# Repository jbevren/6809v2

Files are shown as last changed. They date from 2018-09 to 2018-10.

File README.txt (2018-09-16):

6809v2 single-board computer

(c) 2018 David Wood

This system is a 3.68mhz 6809-based microcomputer with 128k RAM and 8K rom.  It is intended to run 6809-based operating systems that run within 64k of RAM such as FLEX or OS-9 Level I.

All I/O services are provided via a 68681 DUART, either via one of its serial ports or via the extra GPIO pins on the device.

This documentation is primarily a placeholder and will likely be improved as time goes on(TM). ;-)

System memory map:

0000-DFFF	System RAM
E000-FEFF	System ROM  (ROMON=high) or System RAM(ROMON=low)
FF00-FF0F	68681 DUART (see below for I/O definitions)
FF10-FFDF	reserved: Don't use
FFE0-FFFF	System ROM  (ROMON=high) or System RAM(ROMON=low)

DUART I/O Map:
IP0		CTS port A
IP1		CTS port B
IP2		DCD port A (not routed)
IP3		DCD port B (not routed)
IP4		n/c
IP5		SD Data input	Input from Micro SD

OP0		RTS port A
OP1		RTS port B
OP2		RAM A16		A16 to RAM
OP3		RAM A17		A17 to RAM (128k has CE2 here)
OP4		ROMON		High enables the 2764 eprom
OP5		SDCK		Clock output to Micro SD
OP6		SDDO		Data output to Micro SD
OP7		SDCS		Chip select output to Micro SD
		NOTE: The 68681 sets all outputs high on reset
		NOTE: The 68681 inverts its output port bits

A summary of programming-related information is also printed on the pcb.

The memory fitted with a standard 128k-256k sram.  A 512k device can be fitted but the board lacks sufficient hardware to bankswitch more than 256k.
A jumper bridge under the SRAM will allow disconnecting A18 from ground.

Directories:
kicad/		Kicad v<5.0 files used to design the board
sbug/		S-BUG port to the 6809v2 SBC (working)
tests/		Prototype test code segments
sdcard/		SD-Card code (not yet finished)

** Many thanks to Dolo@hackaday.IO for the sdcard sample code and permission for the author to use it as long as the code for the firmware remains free and open! **

License: CC:SA license v4.0
I encourage the sharing and adaptation of this design as long as some credit to me is given in the firmware and/or board design.

Reach me at jbevren@gmail.com

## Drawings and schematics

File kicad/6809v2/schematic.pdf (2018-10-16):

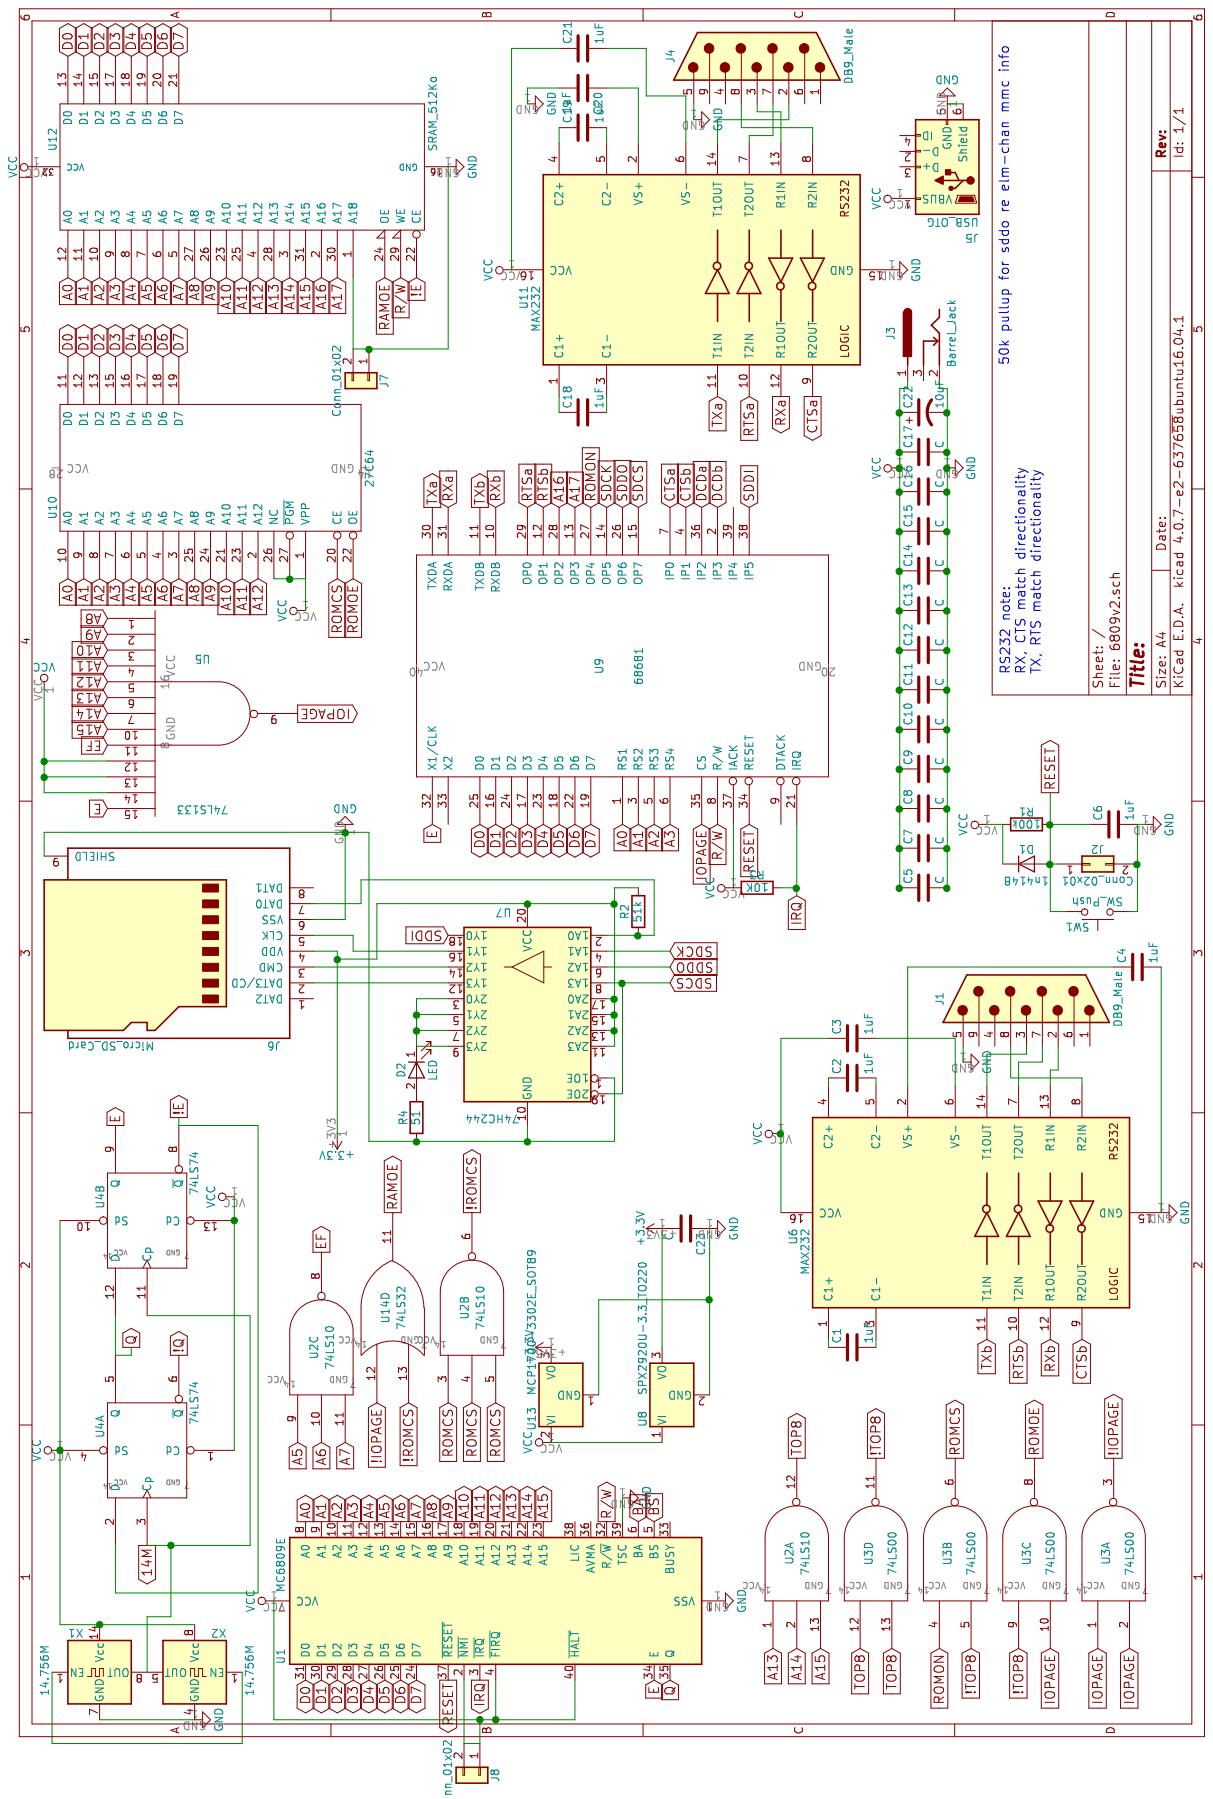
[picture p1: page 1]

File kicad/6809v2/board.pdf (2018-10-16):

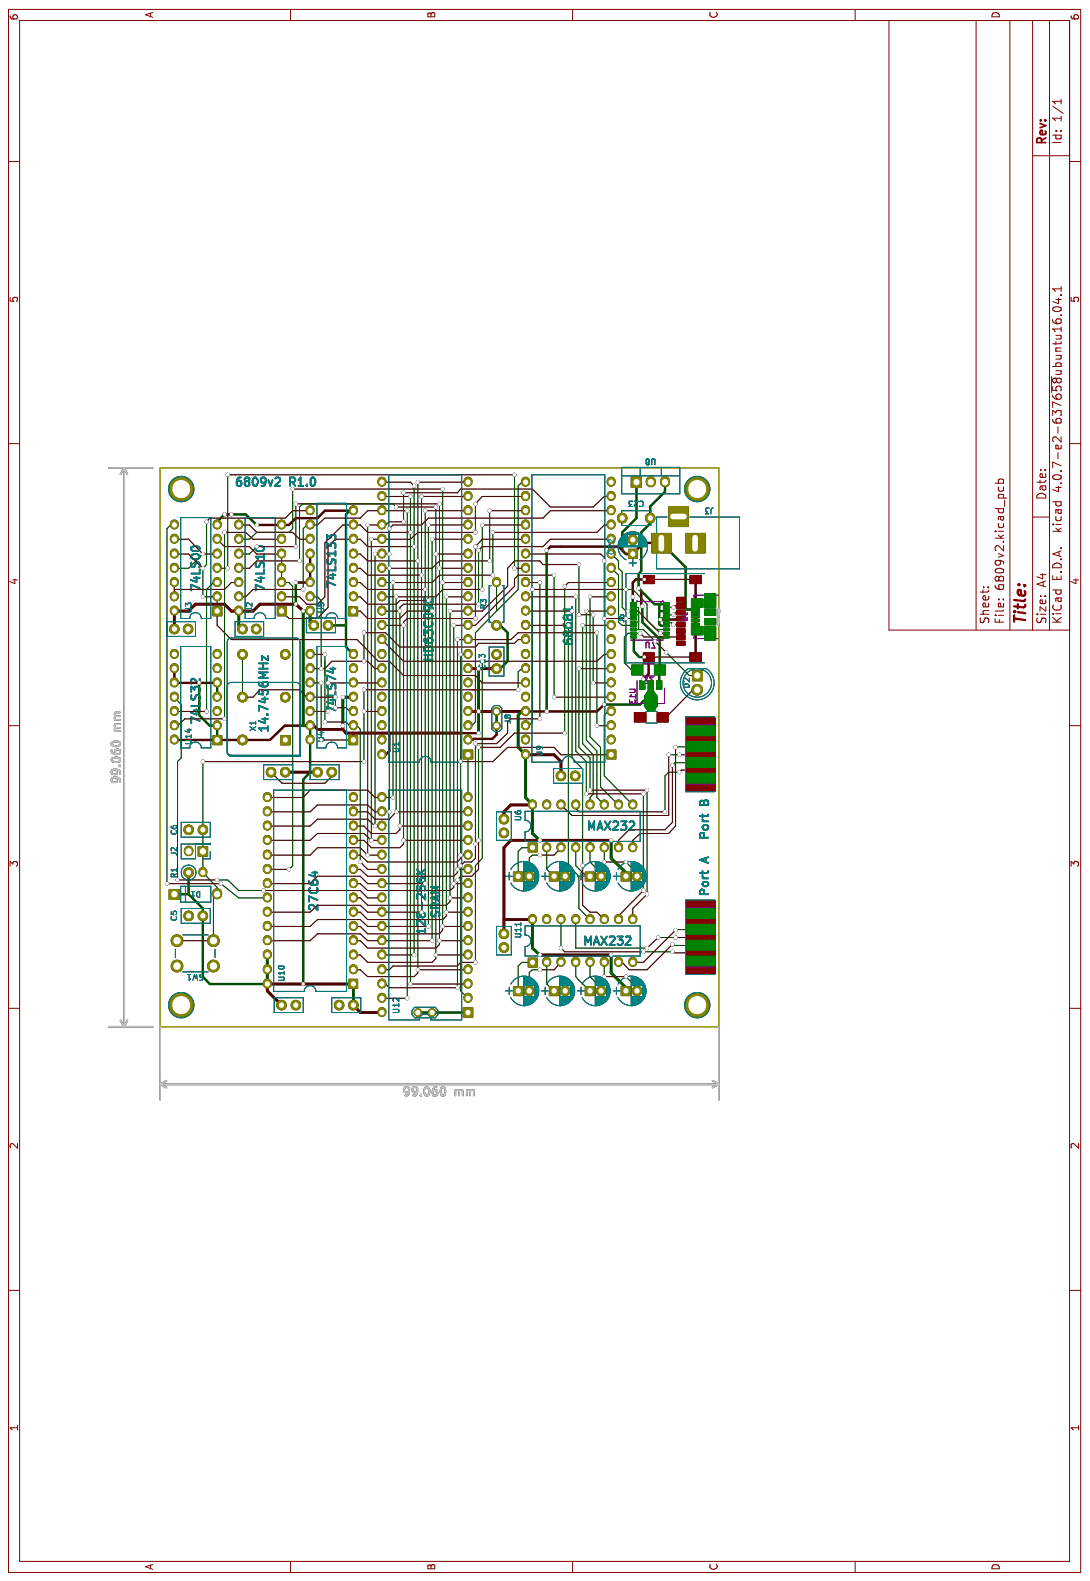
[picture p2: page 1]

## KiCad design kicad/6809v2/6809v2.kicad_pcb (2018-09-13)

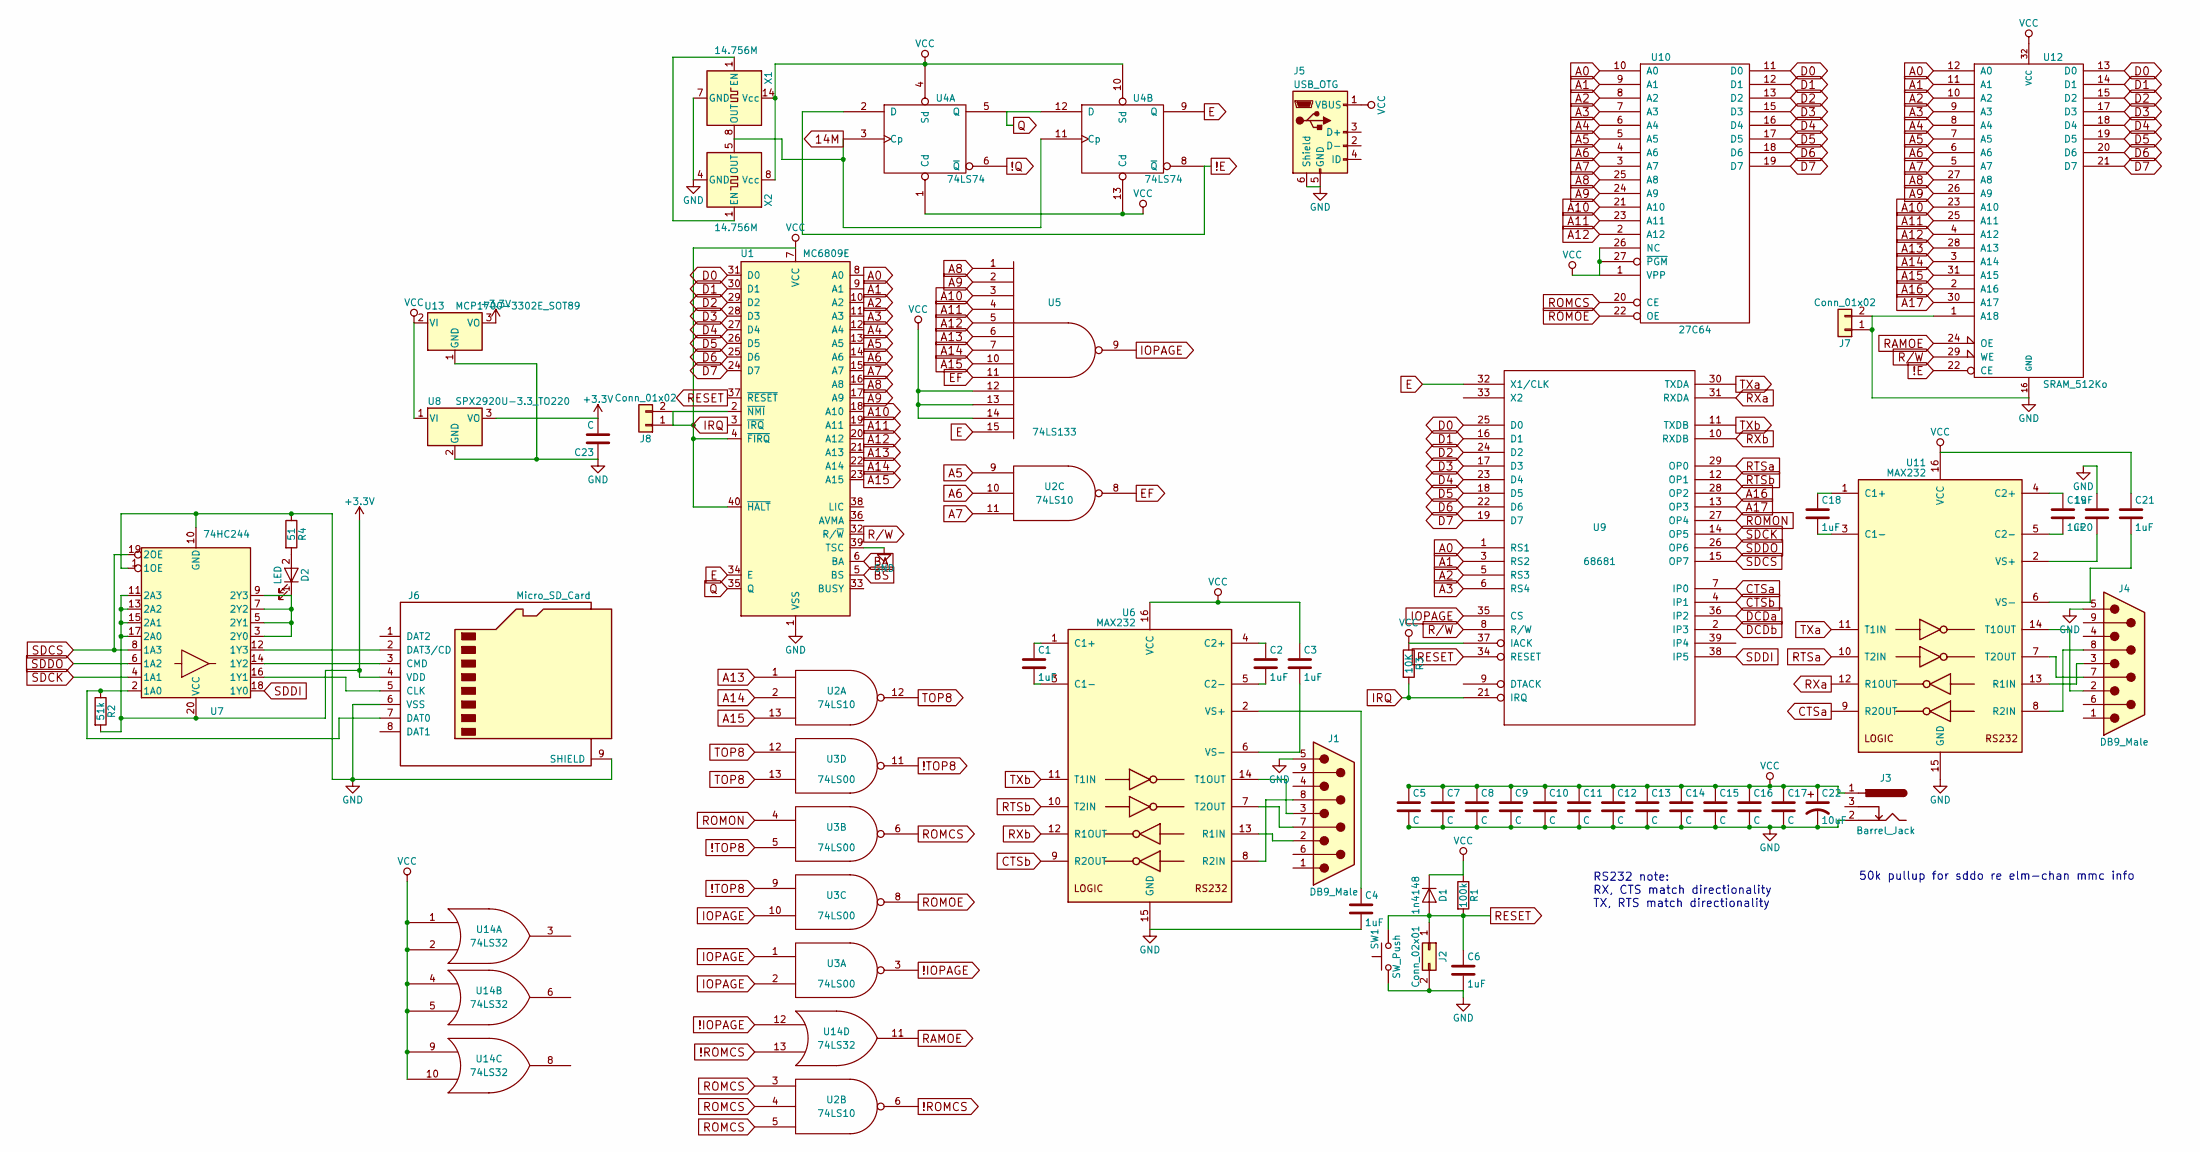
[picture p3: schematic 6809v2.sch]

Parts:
C1, C2, C3, C4, C18, C19, C20, C21: 1uF; CP_Radial_D5.0mm_P2.00mm
C5, C7, C8, C9, C10, C11, C12, C13, C14, C15, C16, C17: C; C_Disc_D5.0mm_W2.5mm_P2.50mm
C6: 1uF; C_Disc_D5.0mm_W2.5mm_P2.50mm
C22: 10uF; CP_Radial_D5.0mm_P2.50mm
C23: C; C_Disc_D5.0mm_W2.5mm_P5.00mm
D1: 1n4148; D_A-405_P7.62mm_Horizontal
D2: LED; LED_D5.0mm
J1, J4: DB9_Male; DB9M_CI
J2: Conn_02x01; Pin_Header_Straight_2x01_Pitch2.54mm
J3: Barrel_Jack; BARREL_JACK
J5: USB_OTG; USB_Micro-B_Molex_47346-0001
J6: Micro_SD_Card; MicroSd_Wurth_693072010801
J7, J8: Conn_01x02; Test_Point_2Pads_Pitch2.54mm_Drill0.8mm
R1: 100k; R_Axial_DIN0207_L6.3mm_D2.5mm_P2.54mm_Vertical
R2: 51k; R_1206_HandSoldering
R3: 10K; R_Axial_DIN0207_L6.3mm_D2.5mm_P7.62mm_Horizontal
R4: 51; R_1206_HandSoldering
SW1: SW_Push; SW_PUSH_6mm
U1: MC6809E; DIP-40_W15.24mm
U2: 74LS10; DIP-14_W7.62mm
U3: 74LS00; DIP-14_W7.62mm
U4: 74LS74; DIP-14_W7.62mm
U5: 74LS133; DIP-16_W7.62mm
U6, U11: MAX232; DIP-16_W7.62mm
U7: 74HC244; SSOP-20_4.4x6.5mm_Pitch0.65mm
U8: SPX2920U-3.3_TO220; TO-220-3_Vertical
U9: 68681; DIP-40_W15.24mm
U10: 27C64; DIP-28_W15.24mm
U12: SRAM_512Ko; DIP-32_W15.24mm
U13: MCP1700-3302E_SOT89; SOT-89-3
U14: 74LS32; DIP-14_W7.62mm
X1: 14.756M; Oscillator_DIP-14
X2: 14.756M; Oscillator_DIP-8

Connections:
14M: U4.3 (Cp), U4.11 (Cp), X1.8 (OUT), X2.5 (OUT)
!E: U4.2 (D), U4.8 (~Q), U12.22 (CE)
!IOPAGE: U3.3, U14.12
!Q: U4.6 (~Q)
!ROMCS: U2.6, U14.13
!TOP8: U3.5, U3.9, U3.11
+3V3: C23.2, J6.4 (VDD), R2.2, U7.11 (2A3), U7.13 (2A2), U7.15 (2A1), U7.17 (2A0), U7.20 (VCC), U8.3 (VO), U13.3 (VO)
A0: U1.8 (A0), U9.1 (RS1), U10.10 (A0), U12.12 (A0)
A1: U1.9 (A1), U9.3 (RS2), U10.9 (A1), U12.11 (A1)
A2: U1.10 (A2), U9.5 (RS3), U10.8 (A2), U12.10 (A2)
A3: U1.11 (A3), U9.6 (RS4), U10.7 (A3), U12.9 (A3)
A4: U1.12 (A4), U10.6 (A4), U12.8 (A4)
A5: U1.13 (A5), U2.9, U10.5 (A5), U12.7 (A5)
A6: U1.14 (A6), U2.10, U10.4 (A6), U12.6 (A6)
A7: U1.15 (A7), U2.11, U10.3 (A7), U12.5 (A7)
A8: U1.16 (A8), U5.1, U10.25 (A8), U12.27 (A8)
A9: U1.17 (A9), U5.2, U10.24 (A9), U12.26 (A9)
A10: U1.18 (A10), U5.3, U10.21 (A10), U12.23 (A10)
A11: U1.19 (A11), U5.4, U10.23 (A11), U12.25 (A11)
A12: U1.20 (A12), U5.5, U10.2 (A12), U12.4 (A12)
A13: U1.21 (A13), U2.1, U5.6, U12.28 (A13)
A14: U1.22 (A14), U2.2, U5.7, U12.3 (A14)
A15: U1.23 (A15), U2.13, U5.10, U12.31 (A15)
A16: U9.28 (OP2), U12.2 (A16)
A17: U9.13 (OP3), U12.30 (A17)
BA: U1.6 (BA)
BS: U1.5 (BS)
CTSa: U9.7 (IP0), U11.9 (R2OUT)
CTSb: U6.9 (R2OUT), U9.4 (IP1)
D0: U1.31 (D0), U9.25 (D0), U10.11 (D0), U12.13 (D0)
D1: U1.30 (D1), U9.16 (D1), U10.12 (D1), U12.14 (D1)
D2: U1.29 (D2), U9.24 (D2), U10.13 (D2), U12.15 (D2)
D3: U1.28 (D3), U9.17 (D3), U10.15 (D3), U12.17 (D3)
D4: U1.27 (D4), U9.23 (D4), U10.16 (D4), U12.18 (D4)
D5: U1.26 (D5), U9.18 (D5), U10.17 (D5), U12.19 (D5)
D6: U1.25 (D6), U9.22 (D6), U10.18 (D6), U12.20 (D6)
D7: U1.24 (D7), U9.19 (D7), U10.19 (D7), U12.21 (D7)
DCDa: U9.36 (IP2)
DCDb: U9.2 (IP3)
E: U1.34 (E), U4.9 (Q), U5.15, U9.32 (X1/CLK)
EF: U2.8, U5.11
GND: C4.2, C5.2, C6.2, C7.2, C8.2, C9.2, C10.2, C11.2, C12.2, C13.2, C14.2, C15.2, C16.2, C17.2, C20.2, C22.2, C23.1, J1.5, J2.2, J3.2, J4.5, J5.5 (GND), J5.6 (Shield), J6.6 (VSS), J6.9 (SHIELD), J7.1, J7.2, R4.1, SW1.1, U1.1 (VSS), U1.39 (TSC), U2.7 (GND), U3.7 (GND), U4.7 (GND), U5.8 (GND), U6.15 (GND), U7.1 (1OE), U7.10 (GND), U8.2 (GND), U9.20 (GND), U10.14 (GND), U11.15 (GND), U12.1 (A18), U12.16 (GND), U13.1 (GND), U14.7 (GND), X1.7 (GND), X2.4 (GND)
IOPAGE: U3.1, U3.2, U3.10, U5.9, U9.35 (CS)
IRQ: R3.2, U1.3 (~IRQ), U9.21 (IRQ)
unnamed: C1.1, U6.1 (C1+)
unnamed: C1.2, U6.3 (C1-)
unnamed: C2.1, U6.4 (C2+)
unnamed: C2.2, U6.5 (C2-)
unnamed: C3.2, U6.6 (VS-)
unnamed: C4.1, U6.2 (VS+)
unnamed: C18.1, U11.1 (C1+)
unnamed: C18.2, U11.3 (C1-)
unnamed: C19.1, U11.4 (C2+)
unnamed: C19.2, U11.5 (C2-)
unnamed: C20.1, U11.2 (VS+)
unnamed: C21.2, U11.6 (VS-)
unnamed: D2.1 (K), U7.3 (2Y0), U7.5 (2Y1), U7.7 (2Y2), U7.9 (2Y3)
unnamed: D2.2 (A), R4.2
unnamed: J1.2, U6.13 (R1IN)
unnamed: J1.3, U6.14 (T1OUT)
unnamed: J1.7, U6.7 (T2OUT)
unnamed: J1.8, U6.8 (R2IN)
unnamed: J4.2, U11.14 (T1OUT)
unnamed: J4.3, U11.13 (R1IN)
unnamed: J4.7, U11.7 (T2OUT)
unnamed: J4.8, U11.8 (R2IN)
unnamed: J6.2 (DAT3/CD), U7.12 (1Y3)
unnamed: J6.3 (CMD), U7.14 (1Y2)
unnamed: J6.5 (CLK), U7.16 (1Y1)
unnamed: J6.7 (DAT0), R2.1, U7.2 (1A0)
unnamed: X1.1 (EN), X2.1 (EN)
Q: U1.35 (Q), U4.5 (Q), U4.12 (D)
R/W: U1.32 (R/~W), U9.8 (R/W), U12.29 (WE)
RAMOE: U12.24 (OE), U14.11
RESET: C6.1, D1.2 (A), J2.1, R1.2, SW1.2, U1.37 (~RESET), U9.34 (RESET)
ROMCS: U2.3, U2.4, U2.5, U3.6, U10.20 (CE)
ROMOE: U3.8, U10.22 (OE)
ROMON: U3.4, U9.27 (OP4)
RTSa: U9.29 (OP0), U11.10 (T2IN)
RTSb: U6.10 (T2IN), U9.12 (OP1)
RXa: U9.31 (RXDA), U11.12 (R1OUT)
RXb: U6.12 (R1OUT), U9.10 (RXDB)
SDCK: U7.4 (1A1), U9.14 (OP5)
SDCS: U7.8 (1A3), U7.19 (2OE), U9.15 (OP7)
SDDI: U7.18 (1Y0), U9.38 (IP5)
SDDO: U7.6 (1A2), U9.26 (OP6)
TOP8: U2.12, U3.12, U3.13
TXa: U9.30 (TXDA), U11.11 (T1IN)
TXb: U6.11 (T1IN), U9.11 (TXDB)
VCC: C3.1, C5.1, C7.1, C8.1, C9.1, C10.1, C11.1, C12.1, C13.1, C14.1, C15.1, C16.1, C17.1, C21.1, C22.1, D1.1 (K), J3.1, J5.1 (VBUS), J8.1, J8.2, R1.1, R3.1, U1.2 (~NMI), U1.4 (~FIRQ), U1.7 (VCC), U1.40 (~HALT), U2.14 (VCC), U3.14 (VCC), U4.1 (Cd), U4.4 (Sd), U4.10 (Sd), U4.13 (Cd), U4.14 (VCC), U5.12, U5.13, U5.14, U5.16 (VCC), U6.16 (VCC), U8.1 (VI), U9.37 (IACK), U9.40 (VCC), U10.1 (VPP), U10.26 (NC), U10.27 (~PGM), U10.28 (VCC), U11.16 (VCC), U12.32 (VCC), U13.2 (VI), U14.1, U14.2, U14.4, U14.5, U14.9, U14.10, U14.14 (VCC), X1.14 (Vcc), X2.8 (Vcc)

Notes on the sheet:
50k pullup for sddo re elm-chan mmc info
RS232 note: RX, CTS match directionality TX, RTS match directionality

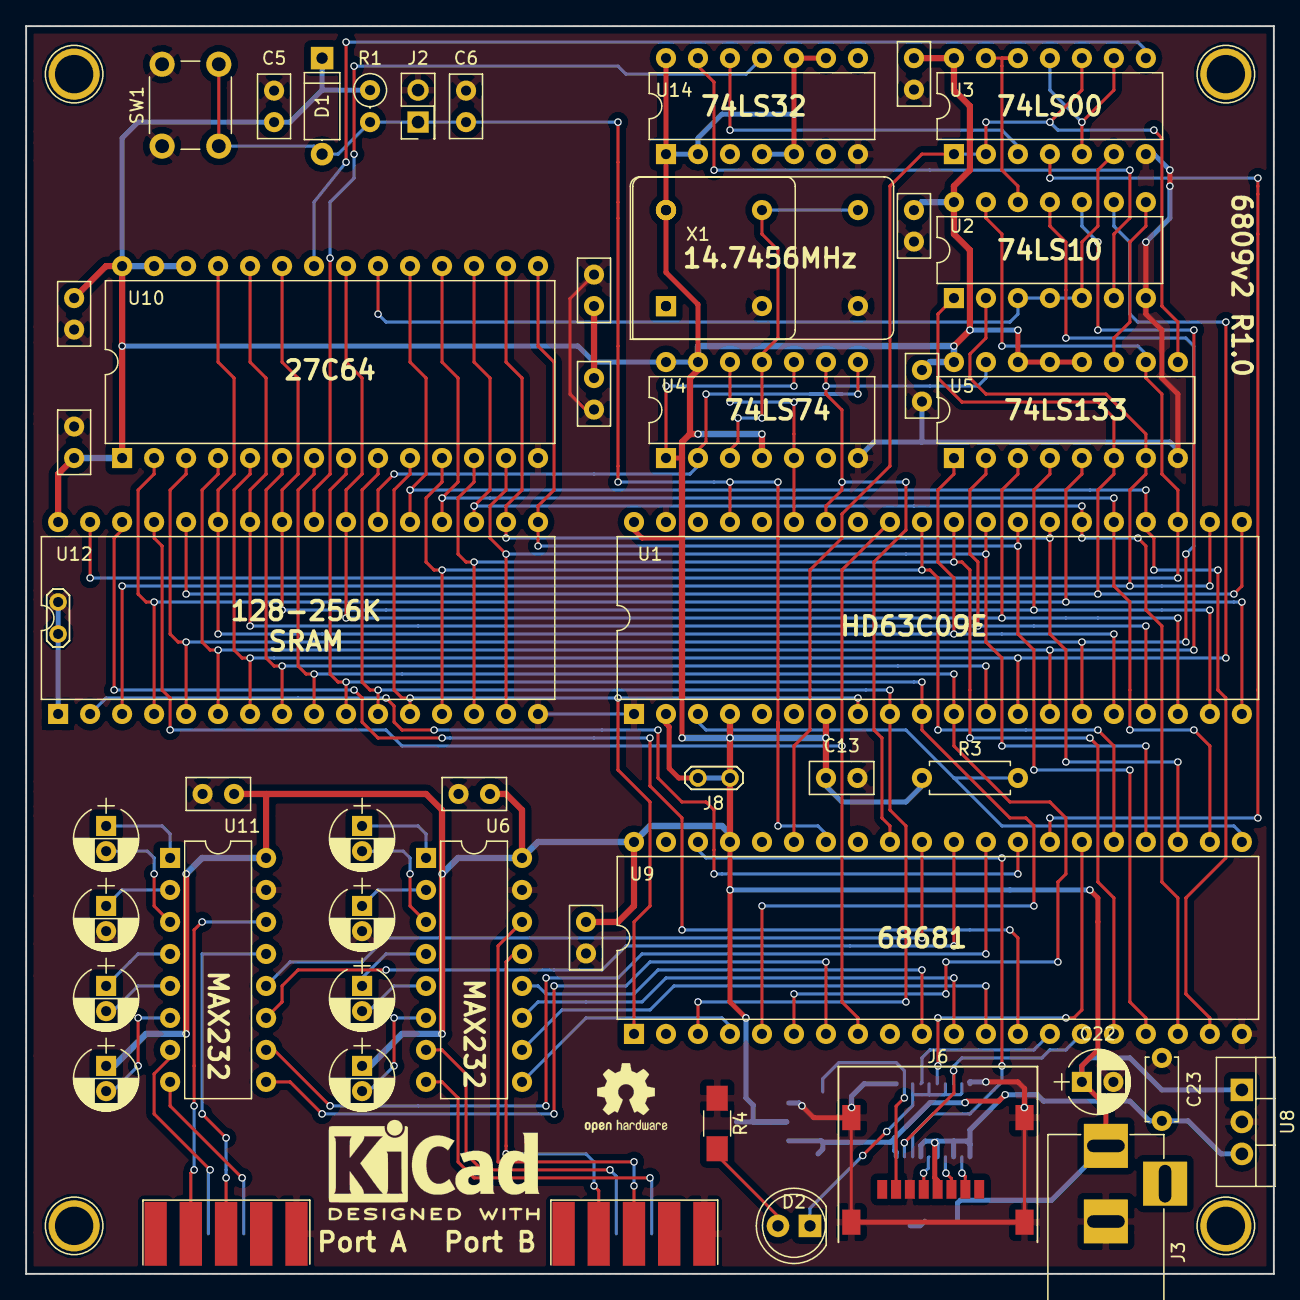
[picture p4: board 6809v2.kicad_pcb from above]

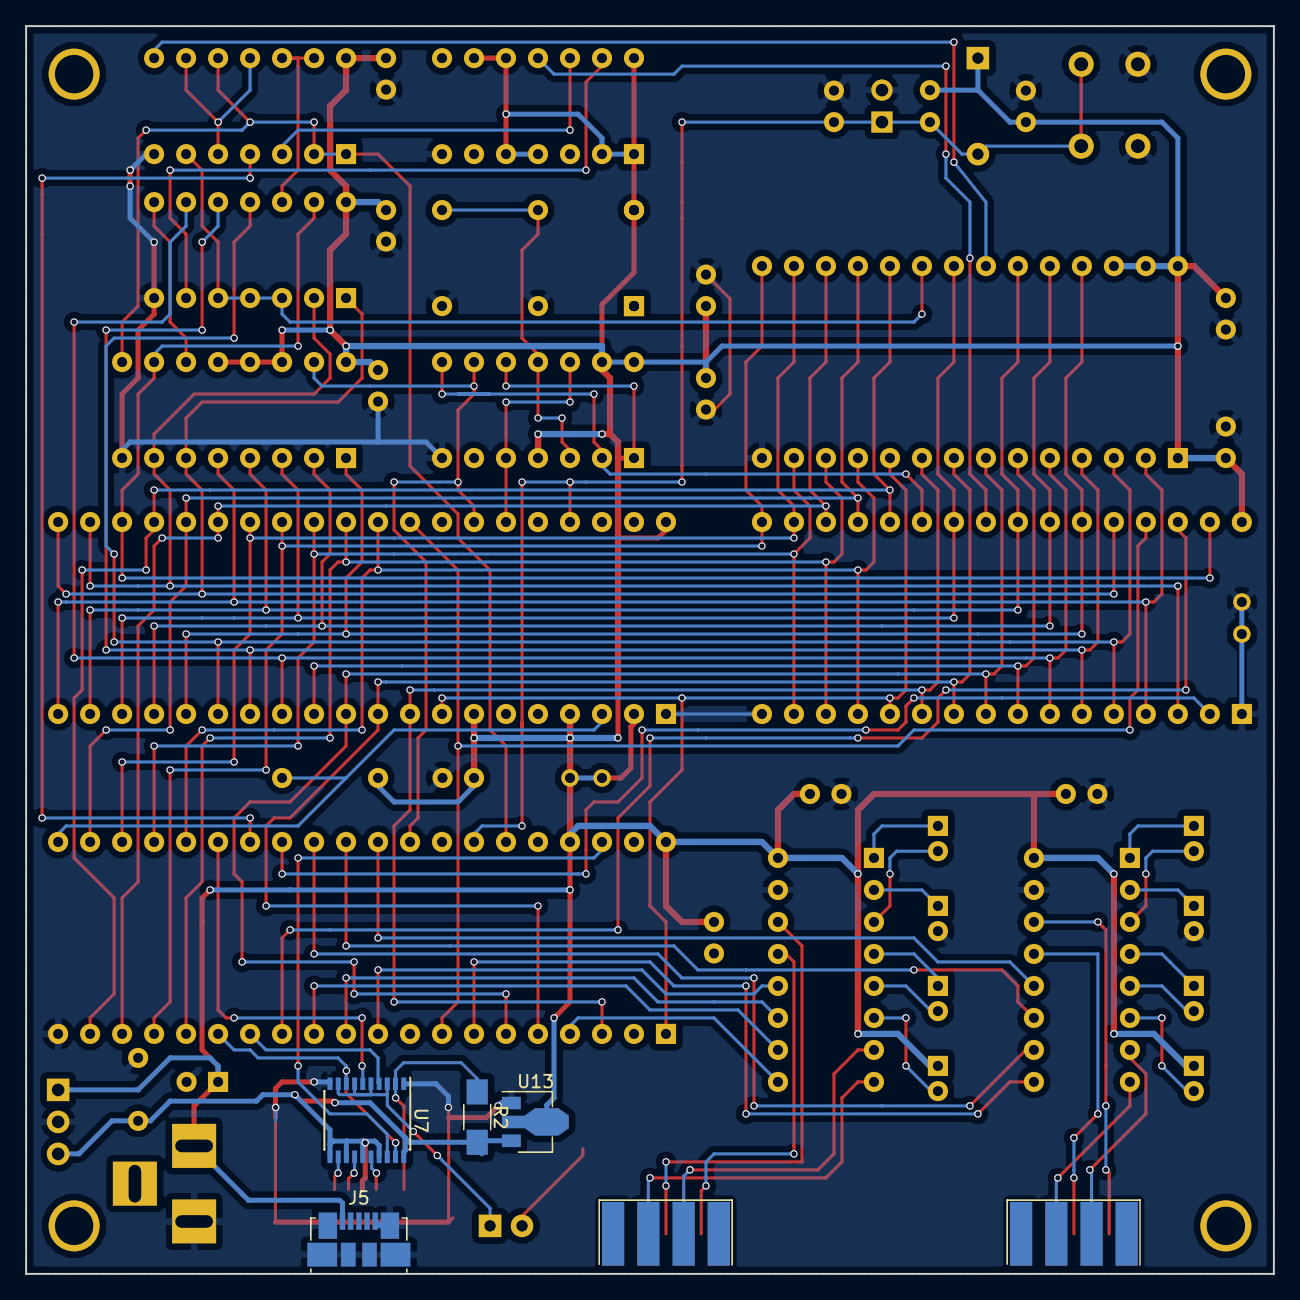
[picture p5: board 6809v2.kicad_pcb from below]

Board: 2 copper layers, 99.1 x 99.1 mm, 54 parts (4 on the bottom side), 85 nets.

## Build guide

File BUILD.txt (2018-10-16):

 ** 6809v2 SBC Assembly instructions **

Parts needed:

#	Part
--	--IC's--
1	63c09E cpu	dip40
1	68681  duart	dip40
1	128k-512k sram	dip32*
1	2764 eprom	dip28
1	74ls10		dip14
1	74ls00		dip14
1	74ls32		dip14
1	74ls133		dip16
1	74lxc244	sop20
2	max232		dip16
1	14.750mhz oscillator
1	3.3v LDO	TO220 or SOT-83

--	--discretes--
13	.1uf decoupling caps
9	1uf  electrolytic caps
1	10uf electrolytic cap
1	51kohm [513] 1206 resistor
1	51 ohm [510] 1206 resistor
1	10k (brown black red) resistor
1	100k (brown black yellow) resistor
1	1n4148 diode
1	6mm push switch
1	LED

--	--ports--
2	solder-cup DB9 male jack
1	wurth 693072010801 (or similar) micro-sd slot
1	micro-b usb jack (optional if barrel jack is fitted, power inlet only)
1	2.5mm barrel jack(optional if usb is fitted)
1	2-pin header

--	--IC sockets (optional)--
1	dip28 .600
1	dip32 .600
2	dip40 .600
4	dip14 .300
3	dip16 .300
1	crystal socket**

* A 512k sram may be fitted, but the board lacks hardware to effectively map more than 256k.  A jumper under the ram socket connects A18 to ground.
** Oscillator cans don't tend to stick well in DIP sockets.  It's recommended to either have a specific socket type or solder the oscillator to the board.

Assembly:
If your board is from VCFMW 13, it's likely that all SMT components are already mounted.  Bare-board purchases may not be this way.

Mount the surface mount components first.  The surrounding components will interfere with soldering later.
* The 74lxc244 may be mounted before the USB jack to aid in drag soldering.

Mount the chip sockets if provided

Mount the oscillator (X1)

Mount the discrete components:
 Value	location(s)
 10uf	C22 (unmarked, near barrel jack )
 1uf	c6 (reset circuit)
 1uf	c18,c19,c20,c21 (near u11)
 1uf	c1,c2,c3,c4 (near u6)
 .1uf	C5 (reset circuit) and near all IC's
 100k	R1 (reset circuit)
  10k	R3 (between CPU and DUART)
 Switch	SW1 (reset circuit)
 diode	D1  (reset circuit)
 3.3v	U8 (near power jack) or U13 (bottom of pcb): Fit one only!

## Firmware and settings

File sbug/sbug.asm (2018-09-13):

	NAM SBUG18 MP-09 MONITOR

* MONITOR PROGRAM FOR THE SOUTHWEST TECHNICAL
* PRODUCTS MP-09 CPU BOARD AS COMMENTED BY....

* ALLEN CLARK            WALLACE WATSON
* 2502 REGAL OAKS LANE   4815 EAST 97th AVE.
* LUTZ, FLA. 33549       TEMPLE TERRACE, FLA. 33617
* PH. 813-977-0347       PH. 813-985-1359

* MODIFIED TO SBUG09 VER 1.8 BY:  RANDY JARRETT
*                                 2561 NANTUCKET DR APT. E
*                                 ATLANTA, GA  30345
*                                 PH. 404-320-1043

* PORTED TO 6809v2 VER 1.0 BY:    David Wood
*                                 jbevren@gmail.com


*       *** COMMANDS ***

* CONTROL A   = ALTER THE "A" ACCUMULATOR
* CONTROL B   = ALTER THE "B" ACCUMULATOR
* CONTROL C   = ALTER THE CONDITION CODE REGISTER
* CONTROL D   = ALTER THE DIRECT PAGE REGISTER
* CONTROL P   = ALTER THE PROGRAM COUNTER
* CONTROL U   = ALTER USER STACK POINTER
* CONTROL X   = ALTER "X" INDEX REGISTER
* CONTROL Y   = ALTER "Y" INDEX REGISTER
* B hhhh      = SET BREAKPOINT AT LOCATION $hhhh
* E ssss-eeee = EXAMINE MEMORY FROM STARTING ADDRESS ssss
*              -TO ENDING ADDRESS eeee.
* G           = CONTINUE EXECUTION FROM BREAKPOINT OR SWI
* I ssssss hhhh = Load sector ssssssss to memory hhhh (512 byes)
* K           = DISPLAY STACK FROM ssss TO $DFC0
* L           = LOAD TAPE
* M hhhh      = EXAMINE AND CHANGE MEMORY LOCATION hhhh
* O ssssss hhhh = Write memory hhhh to sector ssssssss (512 bytes)
* P ssss-eeee = PUNCH TAPE, START ssss TO END eeee ADDR.
* Q ssss-eeee = TEST MEMORY FROM ssss TO eeee
* R           = DISPLAY REGISTER CONTENTS
* S           = Load S19 file to memory (just dump S19 file to console)
* U           = Boot from partition nn (n=0-4; 0=load&exec sector 0)
* V           = Setup SD card and view partition table (USES MEMORY D000-D1FF)
* X           = REMOVE ALL BREAKPOINTS


TSTPAT EQU $55AA  TEST PATTERN



	ORG $DFC0
STACK  RMB 2  TOP OF INTERNAL STACK / USER VECTOR
SWI3   RMB 2  SOFTWARE INTERRUPT VECTOR #3
SWI2   RMB 2  SOFTWARE INTERRUPT VECTOR #2
FIRQ   RMB 2  FAST INTERRUPT VECTOR
IRQ    RMB 2  INTERRUPT VECTOR
SWI    RMB 2  SOFTWARE INTERRUPT VECTOR
SVCVO  RMB 2  SUPERVISOR CALL VECTOR ORGIN
SVCVL  RMB 2  SUPERVISOR CALL VECTOR LIMIT
CPORT  RMB 2  RE-VECTORABLE CONTROL PORT
ECHO   RMB 1  ECHO FLAG
BPTBL  RMB 24 BREAKPOINT TABLE BASE ADDR

* 68681 registers
DUART	EQU $ff00    * DUART at FF00-FF0F
MR1A	EQU 0  * r/w
MR2A	EQU 0  * r/w
SRA	EQU 1  * read
CSRA	EQU 1  * write
BRGTEST EQU 2  * read
CRA	EQU 2  * write
RHRA	EQU 3  * read
THRA	EQU 3  * write
IPCR	EQU 4  * read
ACR	EQU 4  * write
ISR	EQU 5  * read
IMR	EQU 5  * write
CTU	EQU 6  * read
CTUR	EQU 6  * write
CTL	EQU 7  * read
CTLR	EQU 7  * write
MR1B	EQU 8  * r/w
MR2B	EQU 8  * r/w
SRB	EQU 9  * read
CSRB	EQU 9  * write
X16TEST	EQU 10 * read
CRB	EQU 10 * write
RHRB	EQU 11 * read
THRB	EQU 11 * write
IVR	EQU 12 * r/w
IP	EQU 13 * read
OPCR	EQU 13 * write
CNTGO	EQU 14 * read
SOPR	EQU 14 * write
CNTSTP	EQU 15 * read
ROPR	EQU 15 * write



*IC11   EQU $FFF0  DAT RAM CHIP

	ORG $F800
	FDB MONITOR	Restart monitor
	FDB NEXTCMD	Get next monitor command
	FDB INCH	Input char
	FDB INCHE	Input char with echo
	FDB INCHEK	Input Check for character
	FDB OUTCH	Output Character
	FDB PDATA	Print ctrl-d terminated string
	FDB PCRLF	Print CRLF
	FDB PSTRNG	Print string preceded by CRLF
	FDB MONITOR	Restart monitor (deprecated syscall)
*FDB BLKREAD	Read mass storage sector to memory (new)
*FDB BLKWRITE	Write mass storage sector from memory (new)

* MASS STORAGE to use sdcard in 6809v2.
* sdcard (block dev) access:
* sdcard wants
*  cmd: 17=read, 24=write
*  data: 32bit sector address (sdhc) or byte offset (sd)
*        (translate to sector addresses all times via monitor)
* INPUT:
* stack: LBA (32 bits/4 bytes)
* X reg: data pointer
* RETURNS:
* carry set if error
*
* Firmware will init the sdcard when partition table is viewed.

* MONITOR

MONITOR LDX  #RAMVEC POINT TO VECTOR ADDR. STRING
	LDY  #STACK POINT TO RAM VECTOR LOCATION
	LDB  #$10 BYTES TO MOVE = 16
LOOPA	LDA  ,X+ GET VECTOR BYTE
	STA  ,Y+   PUT VECTORS IN RAM / $DFC0-$DFCF
	DECB SUBTRACT 1 FROM NUMBER OF BYTES TO MOVE
	BNE  LOOPA CONTINUE UNTIL ALL VECTORS MOVED

	LDX  #DUART       GET CONTROL PORT ADDR.
	STX  CPORT        STORE ADDR. IN RAM
	LBSR XBKPNT       CLEAR OUTSTANDING BREAKPOINTS
	LDB  #12          CLEAR 12 BYTES ON STACK
CLRSTK  CLR  ,-S
	DECB
	BNE  CLRSTK
	LEAX MONITOR,PCR  SET PC TO SBUG-E ENTRY
	STX  10,S         ON STACK
	LDA  #$D0         PRESET CONDITION CODES ON STACK
	STA  ,S
	TFR  S,U
	LBSR CONINIZ      INITIALIZE CONTROL PORT
	LDX  #MSG1        POINT TO 'SBUG 1.8' MESSAGE
	LBSR PDATA        PRINT MSG


***** NEXTCMD *****

NEXTCMD LDX  #MSG3        POINT TO MSG ">"
	LBSR PSTRNG       PRINT MSG
	LBSR INCH         GET ONE CHAR. FROM TERMINAL
	ANDA #$7F         STRIP PARITY FROM CHAR.
	CMPA #$0D         IS IT CARRIAGE RETURN ?
	BEQ  NEXTCMD      IF CR THEN GET ANOTHER CHAR.
	TFR  A,B          PUT CHAR. IN "B" ACCUM.
	CMPA #$20         IS IT CONTROL OR DATA CHAR ?
	BGE  PRTCMD       IF CMD CHAR IS DATA, PRNT IT
	LDA  #'^          ELSE CNTRL CHAR CMD SO...
	LBSR OUTCH        PRINT "^"
	TFR  B,A          RECALL CNTRL CMD CHAR
	ADDA #$40         CONVERT IT TO ASCII LETTER
PRTCMD	LBSR OUTCH        PRNT CMD CHAR
	LBSR OUT1S        PRNT SPACE
	CMPB #$60
	BLE  NXTCH0
	SUBB #$20


***** DO TABLE LOOKUP *****
*   FOR COMMAND FUNCTIONS

NXTCH0	LDX  #JMPTAB      POINT TO JUMP TABLE
NXTCHR	CMPB ,X+          DOES COMMAND MATCH TABLE ENTRY ?
	BEQ  JMPCMD       BRANCH IF MATCH FOUND
	LEAX 2,X          POINT TO NEXT ENTRY IN TABLE
	CMPX #TABEND      REACHED END OF TABLE YET ?
	BNE  NXTCHR       IF NOT END, CHECK NEXT ENTRY
	LDX  #MSG4        POINT TO MSG "WHAT?"
	LBSR PDATA        PRINT MSG
	BRA  NEXTCMD      IF NO MATCH, PRMPT FOR NEW CMD
JMPCMD	JSR  [,X]         JUMP TO COMMAND ROUTINE
	BRA  NEXTCMD      PROMPT FOR NEW COMMAND


* "G" GO OR CONTINUE

GO	TFR  U,S
RTI	RTI


* "R" DISPLAY REGISTERS

REGSTR	LDX  #MSG5        POINT TO MSG " - "
	LBSR PSTRNG       PRINT MSG
	LBSR PRTSP
	LBSR PRTUS
	LBSR PRTDP
	LBSR PRTIX
	LBSR PRTIY
	LDX  #MSG5        POINT TO MSG " - "
	LBSR PSTRNG       PRINT MSG
	LBSR PRTPC
	LBSR PRTA
	LBSR PRTB
	LBRA PRTCC


* ALTER "PC" PROGRAM COUNTER


ALTRPC LBSR PRTPC $FCF5 PRINT MSG " PC = "
	LBSR OUT1S OUTPUT SPACE
	LBSR IN1ADR GET NEW CONTENTS FOR "PC"
	BVS  ALTPCD EXIT IF INVALID HEX
	STX  10,U POKE IN NEW CONTENTS
ALTPCD RTS


* ALTER "U" USER STACK POINTER


ALTRU LBSR PRTUS $FCCA PRINT MSG " US = "
	LBSR OUT1S OUTPUT SPACE
	LBSR IN1ADR
	BVS  ALTUD
	STX  8,U
ALTUD RTS


*
* ALTER "Y" INDEX REGISTER


ALTRY LBSR PRTIY PRINT MSG " IY = "
	LBSR OUT1S OUTPUT SPACE
	LBSR IN1ADR
	BVS  ALTYD
	STX  6,U   $F8F0
ALTYD RTS


* ALTER "X" INDEX REGISTER


ALTRX LBSR PRTIX $FCE0 PRINT MSG " IX = "
	LBSR OUT1S OUTPUT SPACE
	LBSR IN1ADR
	BVS  ALTXD
	STX  4,U
ALTXD RTS


* ALTER "DP" DIRECT PAGE REGISTER
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
